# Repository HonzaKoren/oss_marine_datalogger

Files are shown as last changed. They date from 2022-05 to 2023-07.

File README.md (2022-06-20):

# OSS Marine Datalogger
OSS datalogger for any sailing fan including support of set of gadgets to get real data to your sailing history.

# Aim
Let's create a set of hardware and software, so you can log your sailing trips under the open data and with as much detail as suits you.
For look under the hood look at [architecture](architecture.md).

# Kick it up&running
A thorough [guide to make your Rasberry your personal tracker](qsg.md)

# External guides and inspirations
[See more](external_links.md)

# Expected hardware
- [Wind speed and direction sensor](wind_measurement.md)
- [Microcontroller Zero W](microcontroller.md)
- Any power bank with USB port to power up whole solution
- GPS/Galileo/GLONASS receiver
- Accelerometer (for anchor alarm and yacht waving compensations)
- Barometer (for weather alarms)

[Bill of material](bom.md)

# Standard wiring
[For no configuration customization use standard wiring schema.](wiring.md)

# Features
- Web interface to be used for visualisations
- Possibility to use WiFi internet connection to share data to any configured server supporting documented REST API
  - Select the data sets to be shared
  - Select the sharing frequency per dataset
  - Global share on/off
- Possibility to set asynchronous commands
  - Managed "cron" jobs
  - Alarms
  - Timed events to start/stop sharing
  - Any command possible to run at given time and frequency in general
- Possibility to set up a reaction to event (now primary intended for anchor alarm)
  - Event sources:
    - Accelerometer (broach logging, dangerous tilt)
    - GPS
      - position offset (anchor alarm)
      - point on map (turning or target point)
      - point connection (i.e. for start or finish during races)
    - Barometer (air pressure drop)
    - Wind speed (reefing alarm)
- Possibility to store Windy data for current location along with tracking data

Want more? Look, if we [plan it](backlog.md).

# Open Points
- Check out the possibility to broadcast data via BTLE to mobile apps
- Source of navy maps

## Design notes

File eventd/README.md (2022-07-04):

# Event daemon

Collects all events, mainly buttons, but in the future an async (cron) events, location offset alarm, environmental thresholds, etc.

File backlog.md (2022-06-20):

# Backlog and ideas

- Create an OSS anemometer
- Create an OSS wind speed sensor
- Log manouvre based on menu action
- Anchor alarm
- Windy forecast download and correlation

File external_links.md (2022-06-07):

# Interesting or guiding links

- [Guide to kick your Raspberry Pi up&running](https://www.raspberrypi.com/documentation/computers/getting-started.html)
- If you want to have your RPi accessible over the network in a [headless setup](https://www.windowscentral.com/how-set-headless-raspberry-pi-windows-10), try this guide
- [Guide to build a GPS tracking device from RPi Zero](https://studyexplorer.medium.com/build-your-own-gps-tracking-system-raspberry-pi-zero-w-2020-6b3ecf55615e)

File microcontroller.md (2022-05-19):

# Microcontroller

[Raspberry Pi Zero W](https://www.raspberrypi.com/products/raspberry-pi-zero-w/) for controlling all data inputs and handling all SW features.

## ToDo
- Verify performance on the go!

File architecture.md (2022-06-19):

# Logger Architecture

## Data collectors
### NMEA GPS module
```mermaid
flowchart TD;
    subgraph "NMEA GPS module";
        Init(Get sensor data) --> SplitRecord(Get first whole record);
        SplitRecord --> IdentifyRecord(Identify NMEA record type);
        IdentifyRecord --> ParseRecord{Parse record by type};
        ParseRecord -->|Location| LocationSave(fa:fa-compass Save position);
        ParseRecord -->|Time| TimeValidate{fa:fa-clock Local time invalid?};
        ParseRecord -->|Direction| DirectionSave(fa:fa-location-arrow Save direction);
        DirectionSave --> DirectionSegment[Direction segment];
        LocationSave --> LocationSegment[Location segment];
        LocationSegment --> ShMemUpdate[Publish to shmem];
        TimeValidate -->|+| SystimeUpdate(Update systime);
        SystimeUpdate --> TimeSegment[Time segment];
        TimeValidate -->|-| TimeSegment[Time segment];
        TimeSegment --> ShMemUpdate(Publish to shmem);
        DirectionSegment --> ShMemUpdate[Publish to shmem];
    end;
```

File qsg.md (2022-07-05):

# Quick Start Guide

## Preparation and tools you'll need
1. SSH client
    1. Linux has SSH client usually as a part of default installation, no pain
    1. Macos has some variety of options, [try this guide](https://www.makeuseof.com/best-ssh-clients-mac/)
    1. Windows has an excellent free SSH terminal emulation called [Putty](https://www.ssh.com/academy/ssh/putty/windows)

## Marine Logger setup
1. Take your Raspberry and make an initial setup as is [very well documented](external_links.md)
1. Connect to your Raspberry as pi user and:
    1. Download latest stable copy of Marine Logger code
    1. Run setup
    1. Connect to Marine Logger web UI (automatically generated admin password is on your SSH terminal screen)
    
### Download latest stable copy of Marine Logger code
```bash
sudo apt update
sudo apt install -y git
cd ~
git clone https://github.com/HonzaKoren/oss_marine_datalogger.git
```

### Run setup
```bash
cd ~/oss_marine_datalogger
./install.sh
```
Or alternatively as a single liner
```bash
sudo apt update && sudo apt install -y git && cd ~ && git clone https://github.com/HonzaKoren/oss_marine_datalogger.git && cd ~/oss_marine_datalogger && ./install.sh
```
### Connect to Marine Logger web UI
Open https://<your_datalogger_IP_address_used_for_SSH_already>/
Default superuser of Marine Datalogger is <em>admin</em>, initial password for that user was generated and shown in the previous step.
If you have lost for any reason the secure password, simply re-run previous step, the installation will be performed again and password re-generated. All your settings made till then will be lost as well. Consider this step a "factory reset".

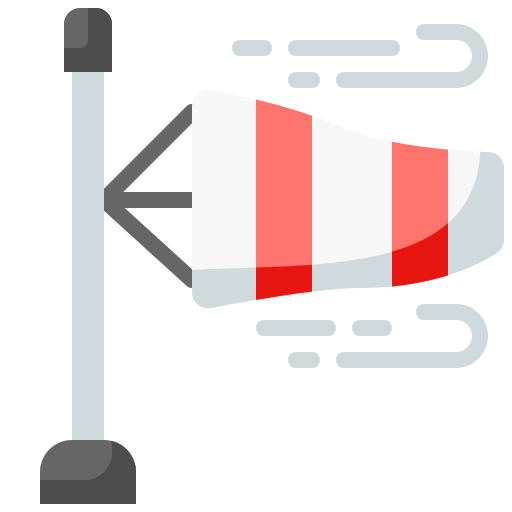
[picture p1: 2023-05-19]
web/static/web/img/windy.512x512.png

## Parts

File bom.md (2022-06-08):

# Bill of Material

1. Microcontroller: [Raspberry Pi 2 B](https://www.raspberrypi.com/products/raspberry-pi-2-model-b/) for future use [Raspberry Pi Zero 2 W](https://www.raspberrypi.com/products/raspberry-pi-zero-2-w/) is intended to save power
1. Location + SoG: [GPS/Beidou/GLONASS/Galileo/QZSS/SBAS Receiver](https://wiki.seeedstudio.com/Grove-GPS-Air530/)
1. USB connectivity for RPi 2 B (Zero 2 W has WiFi built in): Any microdongle ATM I'll use Ralink RT5370 (USB ID 148f:5370)
1. BT connectivity for RPi 2 B (Zero 2 W has BTLE built in): Any microdongle ATM I'll use Cambridge Silicon Radio (USB ID 0a12:0001)
1. Wind measurement - two options:
   1. Wireless over BT [Ultrasonic Portable Solar wind meter](https://calypsoinstruments.com/shop/product/ultrasonic-portable-solar-wind-meter-2)
   1. Wireless over BT, no solar power [Ultrasonic Portable Mini wind meter](https://calypsoinstruments.com/shop/product/cmi1022-ultrasonic-portable-mini-wind-meter-73)
   1. Wired over NMEA 0183 [Veinasa-CXS02B-N NMEA-0183](https://www.aliexpress.com/item/1005003788117590.html) + [NMEA 0183 to USB convertor](https://digitalyacht.co.uk/product/usb-nmea-adaptor/)
   1. Wired over modbus [MINI SIZE ULTRASONIC INTEGRATED WIND SPEED SENSOR AND WIND DIRECTION SENSOR](https://www.aliexpress.com/item/1005004105582503.html)
   1. [Modbus2USB converter](https://www.aliexpress.com/item/1005003076597700.html)
1. Compass
1. High capacity power bank: ATM I'll use solar water proof like [this Sandberg](https://www.czc.cz/sandberg-solarni-outdoorova-powerbanka-24000mah-cerna/233773/produkt)
1. 24x M2x8 metric screw for fixing all featured Grove modules
1. 5x M2.5x8 screw for fixing Rasberry board and for better haptic experience with lif buttons (might be replaced in the future by printed parts)

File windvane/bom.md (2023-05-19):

# Bill of material

## Standards

1. Joining screws ISO 10642 A4 M 2X8 (head border inset 1.32 x 1.1 mm for 3D design)

## Summary
- Joints: 14x Inbus DIN 912 M5x45 inox A4
- Joints: 14x Self locking nut DIN 985 M5 inox A4
- Axis&Windvane tip: 150 mm threaded rod M4 inox A4
- Axis&Windvane tip: 10x Self locking nut DIN 985 M4 inox A4
- Axis: 2x 627-2RS 7x22x7 Full ceramic sealed bearing
- Sensors&Power controller front: 19x M2x6 screw DIN 965 inox inox A4 (eventually DIN 7991, ISO 10642) - Philips or inbus
- Bottom lid&Power controller: 12x M2x8 screw DIN 965 inox inox A4 (eventually DIN 7991, ISO 10642) - Philips or inbus
- Anemometer fixing screw: 1x Inbus headles inox screw M5x5 DIN 914 inox A4
- Boxes insulation: 976 mm insulation 1mm rubber

## Used by parts
- 1x Body tilting joint screw - [Inbus DIN 912 M5x45 A4](http://www.spojovaci-material.net/sp/srouby/valcova-a-zaoblena-hlava/valcova-imbus-din-912/nerezova-ocel/a4-70/sroub-valcova-hlava-inbus-din-912-m5x45-nerez-a4-15187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)
- 2x Tilting joint peg screw - [Inbus DIN 912 M5x45 A4](http://www.spojovaci-material.net/sp/srouby/valcova-a-zaoblena-hlava/valcova-imbus-din-912/nerezova-ocel/a4-70/sroub-valcova-hlava-inbus-din-912-m5x45-nerez-a4-15187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)
- 2x Backstay screw - [Inbus DIN 912 M5x45 A4](http://www.spojovaci-material.net/sp/srouby/valcova-a-zaoblena-hlava/valcova-imbus-din-912/nerezova-ocel/a4-70/sroub-valcova-hlava-inbus-din-912-m5x45-nerez-a4-15187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)
- 5x Holder nuts - [Self locking inox nut DIN 985 M5 A4](http://www.spojovaci-material.net/sp/matice/sestihranne-pojistne/s-nylon-vlozkou-din-985/nerezova-ocel/a4/matice-samojistna-din-985-m5-nerez-a4-15580.html)
- 1x Wind vane axis screw - [65mm A4 závitová tyč]()
- 3x Wind vane shaft nuts - [Self locking inox nut DIN 985 M4 A4](http://www.spojovaci-material.net/sp/matice/sestihranne-pojistne/s-nylon-vlozkou-din-985/nerezova-ocel/a4/matice-samojistna-din-985-m4-nerez-a4-15579.html)
- 3x Fixing screw - [Inbus headless innox screw M5x5 DIN 914 A4](https://eshop.killich.cz/eshop/sroub-m5x5-a4-nerez-staveci-hrot-din-914-iso-4027_9145905005.html)
- 8x Lid & compas fixing screws - [Philips M2x5 DIN 965 A4]()

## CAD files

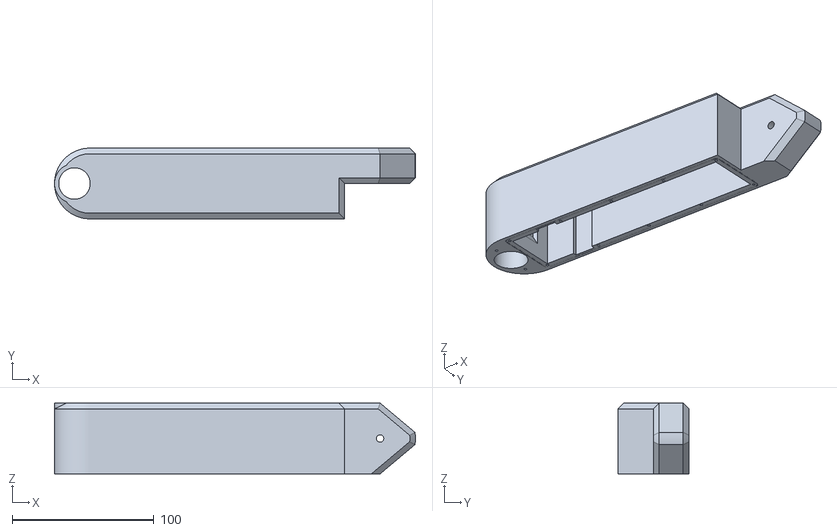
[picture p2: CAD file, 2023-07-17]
windvane/3dprint/Yacht Windvane - Main Body.stl
255.0 x 50.0 x 50.0

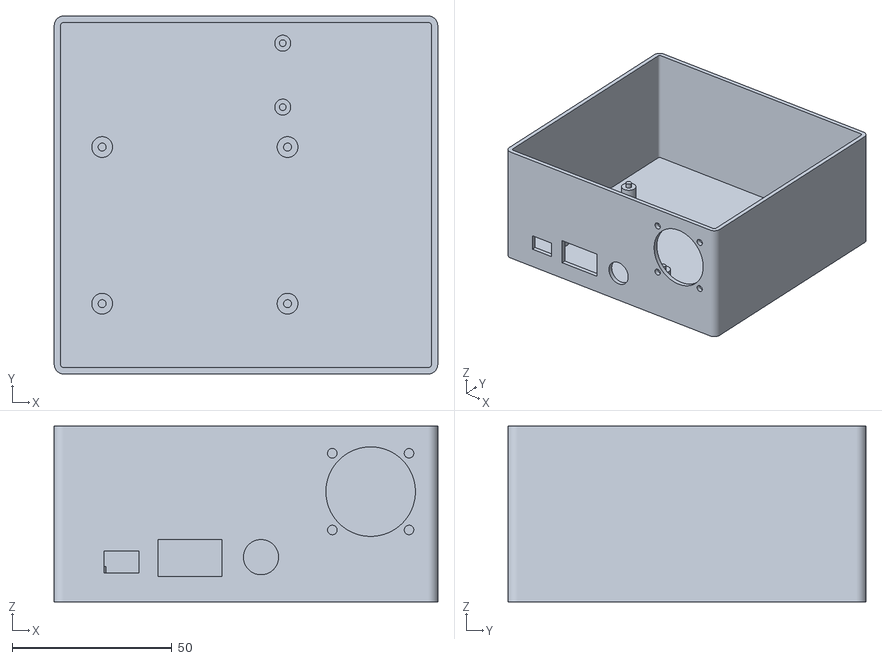
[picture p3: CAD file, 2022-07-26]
3D_print/Box.RPi.2-3-3b.stl
120.0 x 112.0 x 55.0

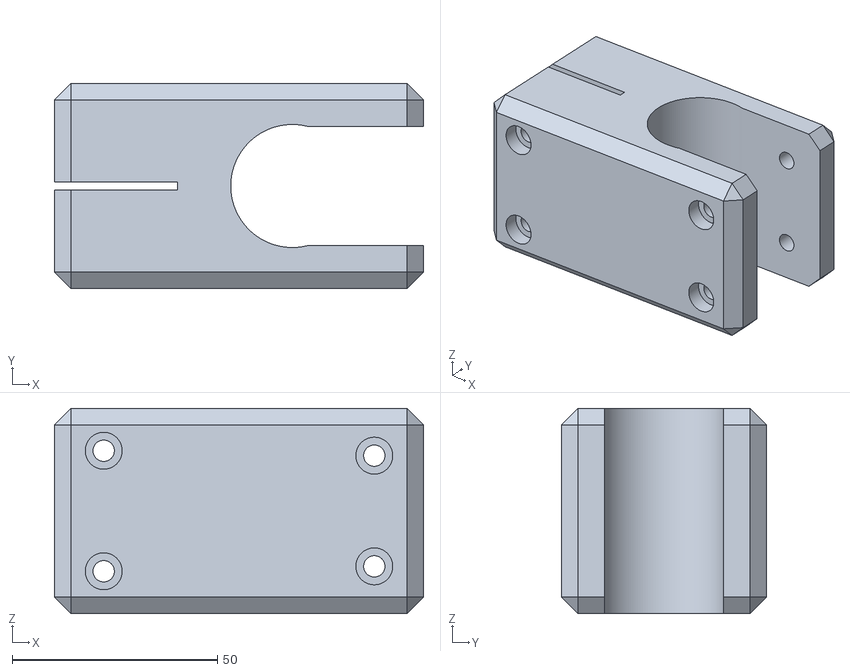
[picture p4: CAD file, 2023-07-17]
windvane/3dprint/Yacht Windvane - Backstay clip.stl
90.0 x 50.0 x 50.0

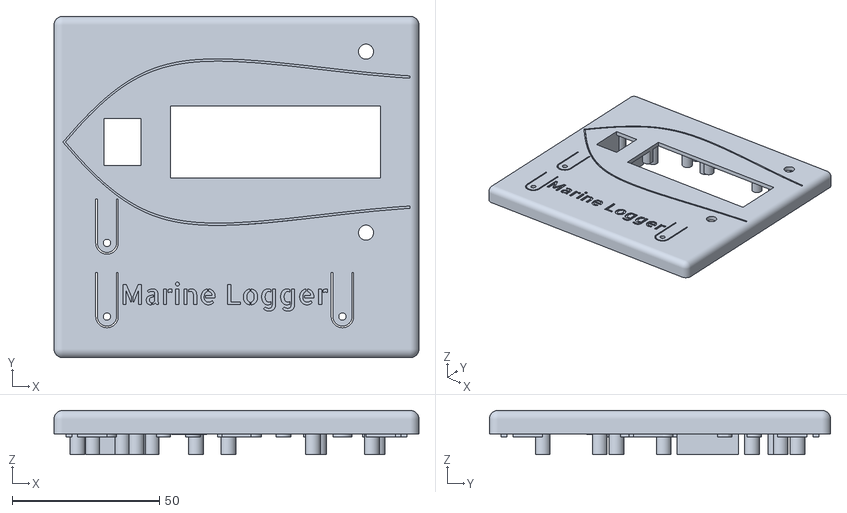
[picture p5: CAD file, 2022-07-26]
3D_print/Lid.RPi.2-3-3b.stl
124.0 x 116.0 x 15.0

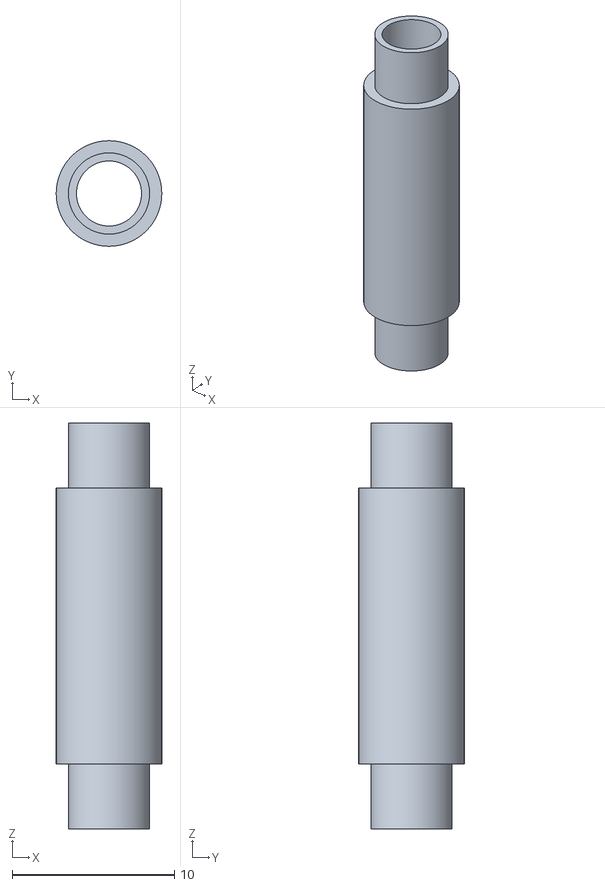
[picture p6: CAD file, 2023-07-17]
windvane/3dprint/Yacht Windvane - Anemometer Core.stl
6.50 x 6.50 x 25.0

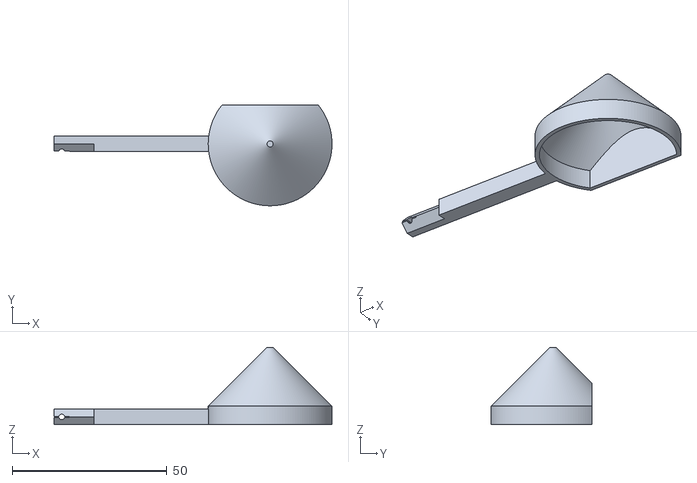
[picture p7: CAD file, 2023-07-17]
windvane/3dprint/Yacht Windvane - Anemometer Cap.stl
89.8 x 32.5 x 25.0

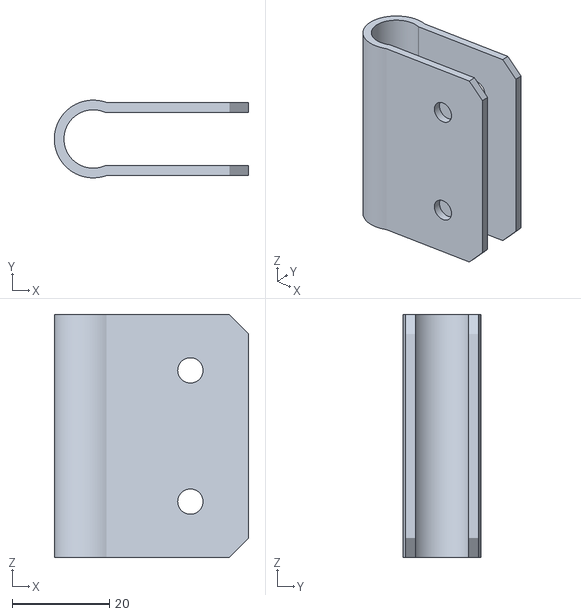
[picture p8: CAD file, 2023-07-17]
windvane/3dprint/Yacht Windvane - Backstay Inset 16-12mm.stl
40.0 x 16.0 x 50.0

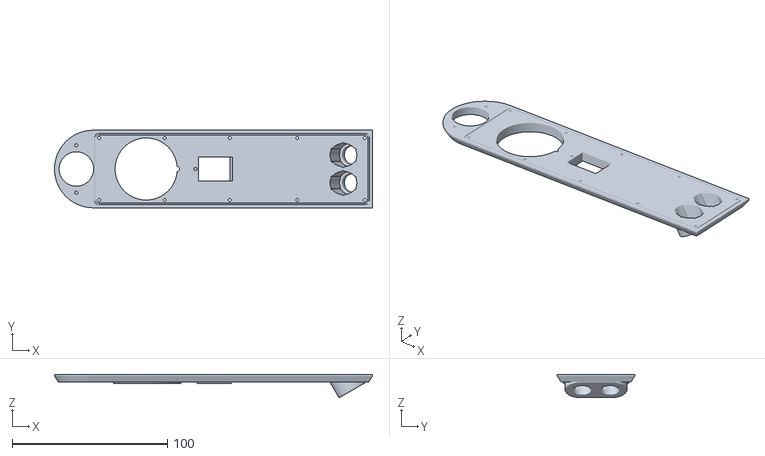
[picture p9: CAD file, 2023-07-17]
windvane/3dprint/Yacht Windvane - Bottom lid.stl
205.0 x 50.0 x 14.9

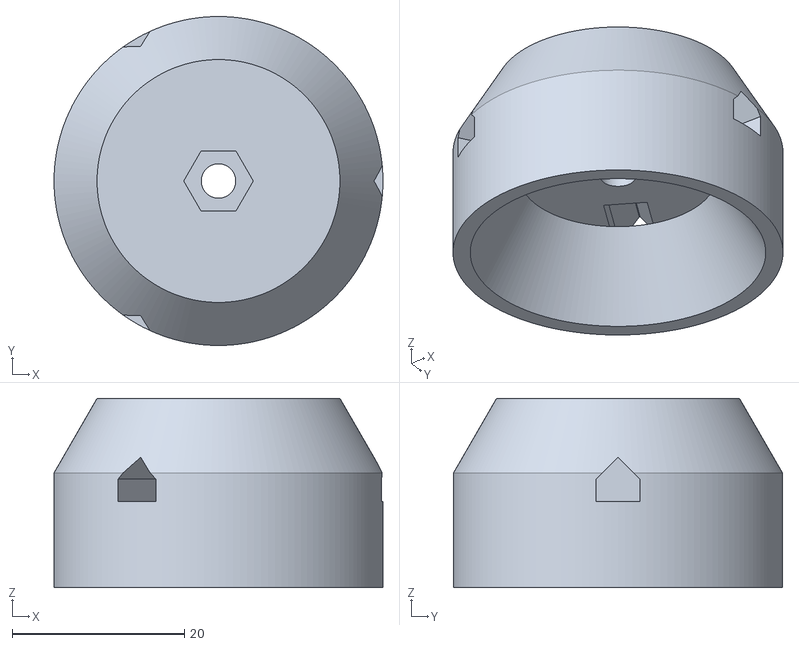
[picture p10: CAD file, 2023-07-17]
windvane/3dprint/Yacht Windvane - Anemometer Body.stl
38.2 x 38.2 x 22.0

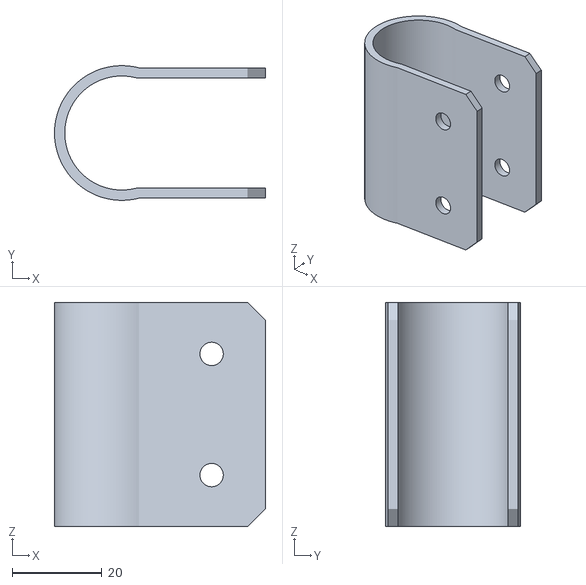
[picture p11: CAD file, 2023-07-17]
windvane/3dprint/Yacht Windvane - Backstay Inset 30mm-1in.stl
47.0 x 30.0 x 50.0

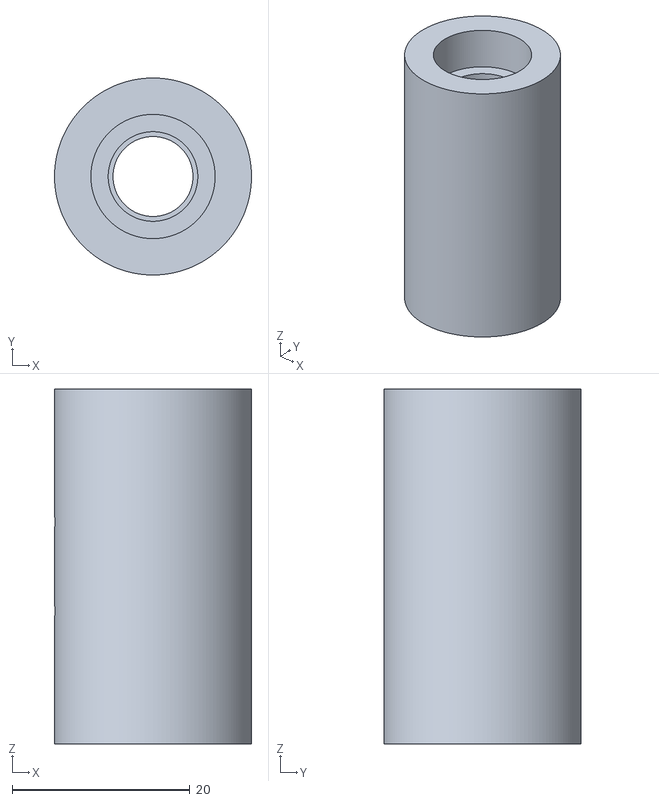
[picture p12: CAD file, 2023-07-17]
windvane/3dprint/Yacht Windvane - Anemometer Holder.stl
22.2 x 22.2 x 40.0

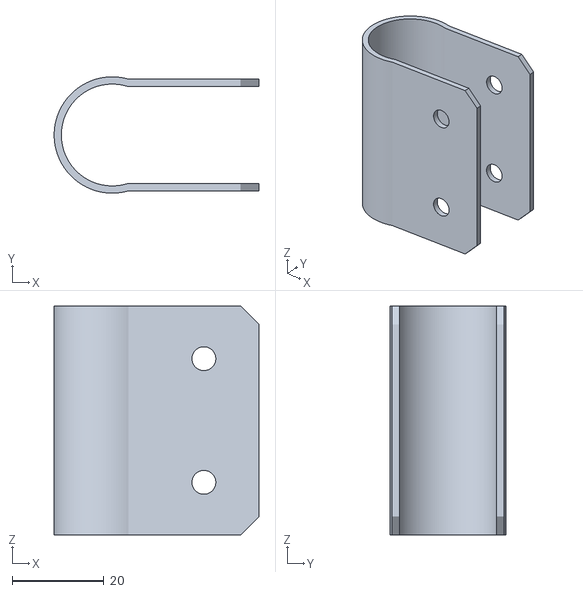
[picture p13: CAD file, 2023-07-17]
windvane/3dprint/Yacht Windvane - Backstay Inset 1in-0.875in.stl
44.7 x 25.4 x 50.0

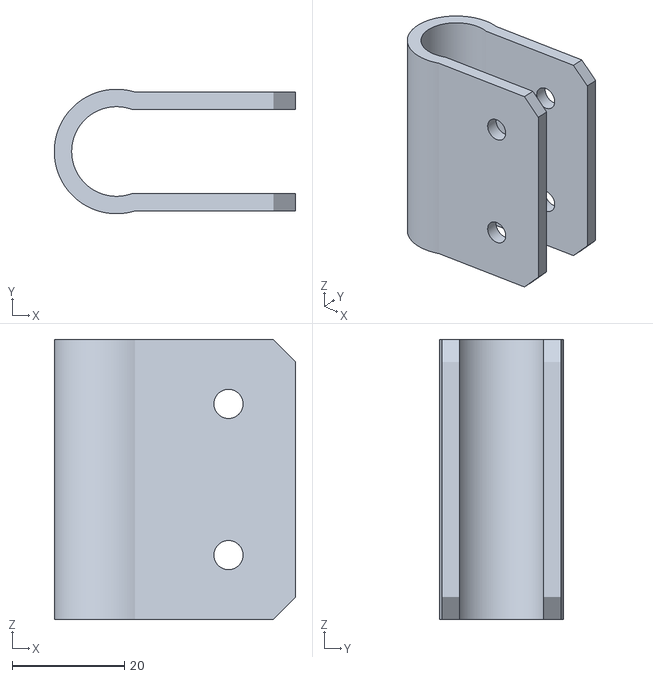
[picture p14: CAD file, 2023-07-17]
windvane/3dprint/Yacht Windvane - Backstay Inset 0.875in-16mm.stl
43.1 x 22.2 x 50.0

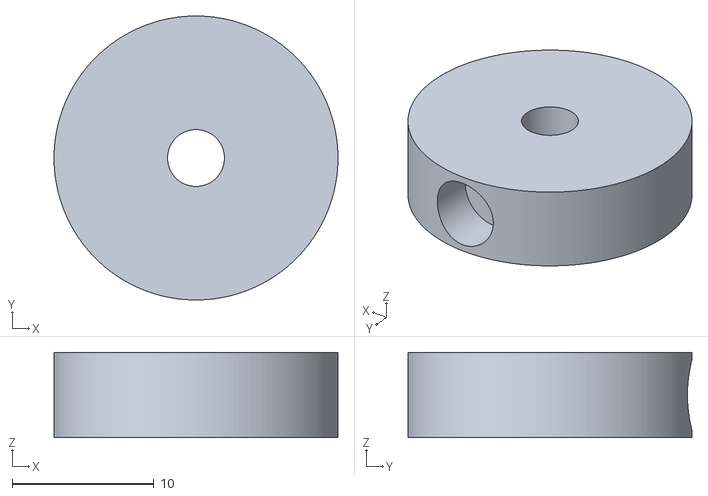
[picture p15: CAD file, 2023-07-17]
windvane/3dprint/Yacht Windvane - Anemometer Magnetic disc.stl
20.0 x 20.0 x 6.00

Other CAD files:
windvane/3dprint/Yacht Windvane - Backstay Inset 12-7mm.stl
windvane/3dprint/Yacht Windvane - ESP8266 socket.stl
windvane/3dprint/Yacht Windvane - SP power controller.stl
windvane/3dprint/Yacht Windvane - Solar Panel Holder.stl
windvane/3dprint/Base Station - Box.stl
windvane/3dprint/Base Station - Lid.stl
windvane/3dprint/Yacht Windvane - Axis mounting tool.stl
windvane/3dprint/Yacht Windvane - ESP8266 socket lid.stl
windvane/3dprint/Yacht Windvane - Flap carrier.stl
windvane/3dprint/Yacht Windvane - Flap.stl
windvane/3dprint/Yacht Windvane - GE outlet key.stl
windvane/3dprint/Yacht Windvane - GX12 Connector Thin Cable Fixer.stl
windvane/3dprint/Yacht Windvane - Joining peg.stl
windvane/3dprint/Yacht Windvane - Nut 7mm key shallow.stl
windvane/3dprint/Yacht Windvane - Nut 7mm key.stl
windvane/3dprint/Yacht Windvane - Peg square inside.stl
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

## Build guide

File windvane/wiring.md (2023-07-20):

# Arduino Nano module wiring

## Components

- Controller: Arduino Nano
  - https://www.laskakit.cz/arduino-nano-r3--atmega328p-klon--nepripajene-piny/
- Local storage **SDC**: SD Card reader (SPI, 3V3/**+5V** (from SPI, not common wire)) - 6wire flat
  - https://dratek.cz/arduino/993-ctecka-microsd-karet.html
  l
  - Connected to Nano SPI top header
- Location **LOC**: Ublox Neo-7M (SoftwareSerial, 3V3/**+5V**) - 5wire JST
  - https://dratek.cz/arduino/1733-gps-satelitni-urceni-polohy-neo-7m-modul.html
  - https://dratek.cz/docs/produkty/0/474/1502177743.pdf
- Temperature&Humidity **DHT**: DHT22 (DigitalRead, **3V3**/+5V) - 3wire JST
  - https://dratek.cz/arduino/1188-dht22-teplomer-a-vlhkomer-digitalni.html
  - https://dratek.cz/docs/produkty/0/56/1455993178.pdf
- Anemometer **ANE**: Hall sensor KY-003 (DigitalRead, 3V3/**+5V**) - 3wire JST
  - https://dratek.cz/arduino/7717-halluv-senzor-modul-ky-003.html
  - S pin for digital input
  - - for GND
  - Middle for VIN
- Wireless Serial **WSER**: HC-12 (SoftwareSerial + DigitalWrite, **3V3**/+5V) - 5wire JST
  - https://dratek.cz/arduino/1394-433mhz-hc-12-si4463-wireless-serial-port-modul-1000m.html
  - https://dratek.cz/docs/produkty/1/1301/1473675078.pdf
- Movement detection **ACC**: MPU6050 Gyroscope (I2C, **3V3**) - 5wire JST
  - https://www.laskakit.cz/arduino-gyroskop-a-akcelerometr-gy-521--mpu6050/
  - https://www.laskakit.cz/user/related_files/mpu-6050_datasheet_v3_4.pdf
- Barometric pressure **BAR**: BMP280 (I2C, **3V3**) - 5wire JST
  - https://www.laskakit.cz/arduino-senzor-barometrickeho-tlaku-a-teploty-bmp280/
- Compass **CMP**: HMC5883L (I2C, **3V3**) - 5wire JST
  - https://www.laskakit.cz/3-osy-magnetometr-a-kompas-hmc5883l/
  - https://github.com/adafruit/Adafruit_HMC5883_Unified
  - https://www.laskakit.cz/user/related_files/hmc5883l.pdf
- Wind direction **DIR**: AS5600 (I2C, 3V3/**+5V**) - 5wire JST
  - https://www.laskakit.cz/magneticky-rotacni-enkoder-as5600--i2c--pwm/
  - https://www.laskakit.cz/user/related_files/bst-bmp280-ds001-11.pdf

## Nano pins

- A0 - Battery voltage
- D2 - D12 - Digital pins
  - D2: Ublox Neo TX SoftwareSerial
  - D3: Ublox Neo RX SoftwareSerial
  - D4: Ublox Neo PPS DigitalRead (time pulse)
  - D5: HC-12 TX SoftwareSerial
  - D6: HC-12 RX SoftwareSerial
  - D7: HC-12 Set DigitalWrite
  - D8: DHT22 DigitalRead 
  - D9: Hall sensor DigitialRead
  - D10
  - D11
  - D12

| Use | PIN | :::<br>SD Card SPI | PIN  | Use |
|:---: |:---:|:---: |:----:|:---: |
| ___ | TX  | | VIN  | ___ |
| ___ | RX  | | GND  | All chip GND |
| ___ | RST | | RST  | ___ |
| ___ | GND | | +5V  | ___ |
| LOC TX white | D2  | | A7 | ___ |
| LOC RX yellow | D3  | | A6 | ___ |
| LOC PPS orange| D4  | | A5 | All I2C SCL  |
| WSER TX white | D5  | | A4 | All I2C SDA  |
| WSER RX yellow | D6  | | A3 | ___ |
| WSER Set orange| D7  | | A2 | ___ |
| DHT | D8  | | A1 | ___ |
| ANE | D9  | | A0 | ___ |
| SDC CS  | D10 | | AREF | ___ |
| ___ | D11 | | 3V3  | All chip VIN |
| ___ | D12 | | D13  | ___ |
| | | USB | | |

### SPI Connector on top of Nano R3 to be used with SDCard module

Taken here: http://lab.dejaworks.com/arduino-nano-sd-card-connection/

When looking from top and miniUSB on left, there are 6 pins on thi right side. This is its use:

|  1 | 2 |
|:----:|:---:|
| GND  | Unused |
| MOSI | SCK |
| VCC  | MISO<br>MOSO |

Sixth pin called CS is connected to digital pin.

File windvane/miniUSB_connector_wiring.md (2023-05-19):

# MiniUSB connector wiring

| Pin | Purpose | Male cable color |
| :-: | :-: | :-- |
| 1.  | VCC | Red |
| 2.  | D- | White |
| 3.  | D+ | Green |
| 4.  | ID | Not connected |
| 5.  | GND | Black |

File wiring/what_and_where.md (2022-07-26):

# Standard Wiring

- RPISER: Air 530 GPS module
- D2: Humidity and temperature sensor DHT11
- D3: Green LED (D3 supports PWM)
- D4: Enter
- D5: Red LED (D5 suipports PWM)
- D6: Buzzer
- D7: Down
- D8: Up
- I2C3: RGB lighted two row LCD (text - 0x3e, RGB - 0x62)
- I2C2: Accelerometer (MPU9250 - 0x68) and barometer (BMP280 - 0x77)

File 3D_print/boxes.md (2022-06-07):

# Boxes

- RPi 2/3/3B box
  - [Onshape CAD model]](https://cad.onshape.com/documents/71e624099aa9e1f631a4b1f3/w/ef475eeba840bf2d2089c468/e/411b5dd9156907e709d1c501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)
  - [STL](Box.RPi.2-3-3b.stl)

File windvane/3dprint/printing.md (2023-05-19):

# Printing suggestions
- Everything 0.20 mm quality profile
- Unless mentioned elsewhere, the filament color is up to you, I used gray, but it's just an aesthetics
- For the best UV stability and sturdy bodies all filaments are PETG
- Fill up 50%

## Main body and Windvane axis (3 parts)
- 6 perimeters
- Supports on base plate
- Body rotate 180° to have top on the plate
- White PETG filament (white for the biggest albedo)

## Bottom lid, Flap carrier, Flap, ESP8266 and AS5600 socket, 3 mounting tools (8 parts)
- Bottom lid rotate 180°
- 5 perimeters
- No supports

## Backstay clip, 2 its insets and Tilting joint (4 parts)
- 6 perimeters
- Supports everywhere

# Windvane axis top (1 part)
- 6 perimeters
- Supports on base plate

# Power drive socket
- Rotation angle to fit the printing board 41.147 °

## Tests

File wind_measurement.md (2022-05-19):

# Wind speed and direction sensor

Let's start with something ready to use despite the fact it is somehow an expensive solution.
[This gadget covers all our needs](https://calypsoinstruments.com/shop/product/ultrasonic-portable-solar-wind-meter-2).

## Future plans
Using 3D printer, compass, RPi Zero, Arduino or any low power consumption microcontroller build up a wind vane and anemometer as cheap as possible.

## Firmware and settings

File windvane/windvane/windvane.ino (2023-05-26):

//
//    FILE: windvane.ino
//  AUTHOR: Jan Kořínek
// PURPOSE: Run windvane/anemometer/DHT22/Adafruit sensors
//    DATE: 2023-04-19
// Sensors: AS5600 - Magnetic rotary encoder
//          DHT22 - Temperature/humidity sensor
//          HMC5883L - magnetic compas
//          

#include <Adafruit_HMC5883_U.h>
#include <Adafruit_BMP280.h>
#include <Adafruit_Sensor.h>
#include <AS5600.h>
#include <DHT.h>
#include <ESP8266HTTPClient.h>
#include <ESP8266mDNS.h>
#include <ESP8266WebServer.h>   // Include the WebServer library
#include <ESP8266WiFi.h>
#include <ESP8266WiFiMulti.h> 
#include <FS.h>
#include <MPU6050_light.h>
#include <SPI.h>
#include <WiFiClient.h>
#include <Wire.h>

// Asynchronous ISR and variables declaration
ICACHE_RAM_ATTR void isrPulseHandler();
volatile bool measure_window_start = false; // Whether first measurement in a time window starts
volatile unsigned long curr_time = 0;       // Current time stamp
volatile unsigned long start_time = 0;      // Timestamp of measurement window start
volatile bool concurrency_lock = false;     // Prevent two semi parallel runs on bounce
volatile float wind = 0;                    // Wind speed in m/s
volatile unsigned long rpm = 0;             // Counted pulses
int wind_probe = D6;                        // Anemometer pin

// Set static IP identity
IPAddress local_IP(192, 168, 192, 102);
// Set your Gateway IP address
IPAddress gateway(192, 168, 192, 254);

IPAddress subnet(255, 255, 255, 0);
IPAddress primaryDNS(192, 168, 192, 254);   //optional


// MultiWiFi setup
ESP8266WiFiMulti wifiMulti;     // Create an instance of the ESP8266WiFiMulti class, called 'wifiMulti'

// Start webserver
ESP8266WebServer server(80);    // Create a webserver object that listens for HTTP request on port 80

// Set up DHT digital pin
#define DHTPIN D4     // Digital pin connected to the DHT sensor
#define DHTTYPE    DHT22     // DHT 22 (AM2302)
DHT dht(DHTPIN, DHTTYPE);

// Barometric pressure
Adafruit_BMP280 bmp; // use I2C interface

// Set up windvane sensor
AS5600 as5600;   //  use default Wire

// Set up compass
Adafruit_HMC5883_Unified mag = Adafruit_HMC5883_Unified(12345);

// Set up accelerometer
MPU6050 mpu(Wire);

void handleRoot();              // function prototypes for HTTP handlers
void handleNotFound();

struct DhtData;   // DHT22 data prototype

struct BmpData;   // BMP280 data prototype

struct MpuData;   // MPU6050 data prototype

unsigned int now = 0;

HTTPClient http;
WiFiClient client;
float cal_compass = 0.0;
float cal_windvane = 0.0;

// Enable platform reset
void(* resetFunc) (void) = 0;

void setup(void){
  Serial.begin(115200);         // Start the Serial communication to send messages to the computer
  // delay(10);
  Serial.println('\n');

  // Set up anemometer pin
  pinMode(wind_probe,INPUT_PULLUP);
  attachInterrupt(digitalPinToInterrupt(wind_probe), isrPulseHandler, FALLING);  //  function for creating external interrupts at wind_probe pin on falling (HIGH to LOW)
  start_time = micros();
  
  // Set up FS
  bool res = SPIFFS.begin();

  // Start DHT reader
  dht.begin();

  // Start compass reader
  mag.begin();

  // Start magnetic encoder
  as5600.begin(4);  //  set direction pin.
  as5600.setDirection(AS5600_CLOCK_WISE);  // default, just be explicit.

  // Set up default APs to try to connect to
  wifiMulti.addAP("koreni", "heslicko");   // add Wi-Fi networks you want to connect to
  wifiMulti.addAP("ossml", "MarineLogger");
  // wifiMulti.addAP("ssid_from_AP_3", "your_password_for_AP_3");

  Serial.println("Connecting ...");
  int i = 0;
  while (wifiMulti.run() != WL_CONNECTED) { // Wait for the Wi-Fi to connect: scan for Wi-Fi networks, and connect to the strongest of the networks above
    delay(50);
    Serial.print('.');
  }
  if (WiFi.SSID() == "ossml") {
    WiFi.config(local_IP, gateway, subnet, primaryDNS);
    Serial.println("Connected to an implicit SSID, setting static IP.");
  }
  Serial.println('\n');
  Serial.print("Connected to ");
  Serial.println(WiFi.SSID());              // Tell us what network we're connected to
  Serial.print("IP address: ");
  Serial.println(WiFi.localIP());           // Send the IP address of the ESP8266 to the computer

  if (MDNS.begin("meteo")) {              // Start the mDNS responder for esp8266.local
    Serial.println("mDNS responder started");
    MDNS.addService("http", "tcp", 80);
  } else {
    Serial.println("Error setting up MDNS responder!");
  }

  // Start barometer
  unsigned status;
  status = bmp.begin(0x76);
  if (!status) {
    Serial.println(F("Could not find a valid BMP280 sensor, check wiring or "
                      "try a different address!"));
    Serial.print("SensorID was: 0x"); Serial.println(bmp.sensorID(),16);
    Serial.print("        ID of 0xFF probably means a bad address, a BMP 180 or BMP 085\n");
    Serial.print("   ID of 0x56-0x58 represents a BMP 280,\n");
    Serial.print("        ID of 0x60 represents a BME 280.\n");
    Serial.print("        ID of 0x61 represents a BME 680.\n");
    while (1) delay(10);
  } else {
    Serial.print("BMP280 init status: ");
    Serial.println(status);
  }
  bmp.setSampling(Adafruit_BMP280::MODE_FORCED,     /* Operating Mode. */
                Adafruit_BMP280::SAMPLING_X2,     /* Temp. oversampling */
                Adafruit_BMP280::SAMPLING_X16,    /* Pressure oversampling */
                Adafruit_BMP280::FILTER_X16,      /* Filtering. */
                Adafruit_BMP280::STANDBY_MS_500); /* Standby time. */

  // Start MPU6050
  byte mpu_status = mpu.begin();
  Serial.print(F("MPU6050 status: "));
  Serial.println(mpu_status);
  // Calibrate
  mpu.calcOffsets(true,true);
  
  server.enableCORS(true);
  server.on("/resetUnit", resetFunc);       // Perform unit reset on demand
  server.on("/data.json", handleJSON);      // Serve dynamic data as JSON
  server.on("/data.txt", handleTXT);        // Serve dynamic data as Prometheus plain text
  server.serveStatic("/", SPIFFS, "/index.html");
  server.serveStatic("/", SPIFFS, "/");
  server.onNotFound(handleNotFound);        // When a client requests an unknown URI (i.e. something other than "/"), call function "handleNotFound"

  server.begin();                           // Actually start the server
  Serial.println("HTTP server started");

  // Get calibration from master node
  http.begin(client, "http://192.168.192.101/static/calibration/compass.txt");
  int httpCode = http.GET();
  String compass = http.getString();
  Serial.print("Compass calibration offset ");
  Serial.println(compass);
  cal_compass = compass.toFloat() * PI / 180;
  http.end();
  http.begin(client, "http://192.168.192.101/static/calibration/windvane.txt");
  httpCode = http.GET();
  String windvane = http.getString();
  Serial.print("Windvane calibration offset ");
  Serial.println(windvane);
  cal_windvane = windvane.toFloat();
  http.end();
  now = millis();
}

void loop(void){
  server.handleClient();                    // Listen for HTTP requests from clients
}

struct DhtData
{
  String temperature;
  String humidity;
};

struct BmpData
{
  String temperature;
  String pressure;
  String altitude;
};

struct MpuData
{
  String temperature;
  String accX;
  String accY;
  String accZ;
  String accAngleX;
  String accAngleY;
  String angleX;
  String angleY;
  String angleZ;
  String gyroX;
  String gyroY;
  String gyroZ;
};

DhtData getDHT() {
  // DHT22 
  DhtData _dht;
  if(isnan(dht.readTemperature())) {
    _dht.temperature = String(-65535);
  } else {
    _dht.temperature = String(dht.readTemperature());
  }
  if(isnan(dht.readHumidity())) {
    _dht.humidity = String(-65535);
  }
    _dht.humidity = String(dht.readHumidity());
  return _dht;
}

BmpData getBMP() {
  // BMP init
  BmpData _bmp;
  if (bmp.takeForcedMeasurement()) {
    _bmp.temperature = String(bmp.readTemperature());
    _bmp.pressure = String(bmp.readPressure());
    _bmp.altitude = String(bmp.readAltitude());
  } else {
    _bmp.temperature = String("-0.0");
    _bmp.pressure = String("-0.0");
    _bmp.altitude = String("-0.0");
  }
  return _bmp;
}

MpuData getMPU() {
  // MPU init
  MpuData _mpu;
  mpu.update();
  _mpu.temperature = String(mpu.getTemp());
  _mpu.accX = String(mpu.getAccX());
  _mpu.accY = String(mpu.getAccY());
  _mpu.accZ = String(mpu.getAccZ());
  _mpu.accAngleX = String(mpu.getAccAngleX());
  _mpu.accAngleY = String(mpu.getAccAngleY());
  _mpu.angleX = String(mpu.getAngleX());
  _mpu.angleY = String(mpu.getAngleY());
  _mpu.angleZ = String(mpu.getAngleZ());
  _mpu.gyroX = String(mpu.getGyroX());
  _mpu.gyroY = String(mpu.getGyroY());
  _mpu.gyroZ = String(mpu.getGyroZ());
  return _mpu;
}

String getVoltage() {
  float analog = analogRead(A0);
  float voltage = 4.2 * (analog / 1024);  // Max ESP input voltage * Digital sensor load
  return String(voltage);
};

String getDirection() {
  // Compass data
  sensors_event_t magData; 
  mag.getEvent(&magData);
  float azimuth = atan2(magData.magnetic.y, magData.magnetic.x) + cal_compass;
  if(azimuth < 0)
    azimuth += 2*PI;
  if(azimuth > 2*PI)
    azimuth -= 2*PI;  
  float azimuthDg = azimuth * 180/M_PI;
  return String(azimuthDg);  
}

String getWind() {
  // AS5600 wind direction
  float apparentWind = as5600.rawAngle() * AS5600_RAW_TO_DEGREES + cal_windvane;
  if(apparentWind < 0)
    apparentWind += 360;
  if(apparentWind > 360)
    apparentWind -= 360;  
  return String(apparentWind);
}

void handleJSON() {
  DhtData myDht = getDHT();
  BmpData myBmp = getBMP();
  MpuData myMpu = getMPU();
  
  String response = "{\"humidity_dht\": ";
  response += myDht.humidity;
  response += ", \"temperature_dht\": ";
  response += myDht.temperature;
  response += ", \"inner_temperature\": ";
  response += myBmp.temperature;
  response += ", \"air_pressure\": ";
  response += myBmp.pressure;
  response += ", \"altitude\": ";
  response += myBmp.altitude;
  response += ", \"direction\": ";
  response += getDirection();
  response += ", \"apparent_wind\": ";
  response += getWind();
  response += ", \"temperature_mpu\": ";
  response += myMpu.temperature;
  response += ", \"accX\": ";
  response += myMpu.accX;
  response += ", \"accY\": ";
  response += myMpu.accY;
  response += ", \"accZ\": ";
  response += myMpu.accZ;
  response += ", \"accAngleX\": ";
  response += myMpu.accAngleX;
  response += ", \"accAngleY\": ";
  response += myMpu.accAngleY;
  response += ", \"angleX\": ";
  response += myMpu.angleX;
  response += ", \"angleY\": ";
  response += myMpu.angleY;
  response += ", \"angleZ\": ";
  response += myMpu.angleZ;
  response += ", \"gyroX\": ";
  response += myMpu.gyroX;
  response += ", \"gyroY\": ";
  response += myMpu.gyroY;
  response += ", \"gyroZ\": ";
  response += myMpu.gyroZ;
  response += ", \"wind_speed\": ";
  response += String(wind);
  response += ", \"wind_pulses\": ";
  response += String(rpm);
  response += ", \"a0_data\": ";
  response += String(analogRead(A0));
  response += ", \"battery_voltage\": ";
  response += getVoltage();
  response += ", \"runtime\": ";
  response += String(millis());
  response += "}";
  server.send(200, "application/json", response);
}

void handleTXT() {
  DhtData myDht = getDHT();  // Read DHT
  BmpData myBmp = getBMP();
  MpuData myMpu = getMPU();
  // Acceleration
  // Wind speed
  // Timestamp
  // Calibrations 
  // Battery voltage and percentage
  // HTTP server request count
  String response = "humidity_dht " + myDht.humidity + "\n";
  response += "temperature_dht " + myDht.temperature + "\n";
  response += "inner_temperature " + myBmp.temperature + "\n";
  response += "air_pressure " + myBmp.pressure+ "\n";
  response += "altitude " + myBmp.altitude + "\n";
  response += "direction " + getDirection() + "\n";
  response += "apparent_wind " + getWind() + "\n";
  response += "temperature_mpu " + myMpu.temperature + "\n";
  response += "accX " + myMpu.accX + "\n";
  response += "accY " + myMpu.accY + "\n";
  response += "accZ " + myMpu.accZ + "\n";
  response += "accAngleX " + myMpu.accAngleX + "\n";
  response += "accAngleY " + myMpu.accAngleY + "\n";
  response += "angleX " + myMpu.angleX + "\n";
  response += "angleY " + myMpu.angleY + "\n";
  response += "angleZ " + myMpu.angleZ + "\n";
  response += "gyroX " + myMpu.gyroX + "\n";
  response += "gyroY " + myMpu.gyroY + "\n";
  response += "gyroZ " + myMpu.gyroZ + "\n";
  response += "wind_speed " + String(wind) + "\n";
  response += "wind_pulses " + String(rpm) + "\n";
  response += "a0_data " + String(analogRead(A0)) + "\n";
  response += "battery_voltage " + getVoltage() + "\n";
  response += "runtime " + String(millis()) + "\n";
  server.send(200, "text/plain", response);
}

void handleNotFound(){
  server.send(404, "text/plain", "404: Not found"); // Send HTTP status 404 (Not Found) when there's no handler for the URI in the request
}

//ISR function catching anemometer pulse
ICACHE_RAM_ATTR void isrPulseHandler()
{
  if(!concurrency_lock) {
    concurrency_lock = true;
    // Parallel run debounce
    // Get now to use it for pulse length and debounce
    curr_time = micros();
    // Debounce measurement sooner, than 20 ms
    unsigned long pulse_duration = curr_time - start_time;
    if(pulse_duration > 750) {
      if(!measure_window_start) {
        float pulse_length = (float)(pulse_duration / 1000);  // Pulse length in seconds
        wind = (float)(2400000.0 / (pulse_duration * 3.6));    // Device constant 1 pulse per second = 2,4 km/h, calc in m/s
        rpm++;
      }
      // Measurement was considered valid, shift start time
      start_time = curr_time;
      // Next measurement will not be taken as initial
      measure_window_start = false;
    }
    concurrency_lock = false;
  }
}

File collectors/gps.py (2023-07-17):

#!/usr/bin/env python3
import io
import os
from pathlib import Path
from shutil import move
import time

import pynmea2
import serial


ser = serial.Serial('/dev/serial0', 9600, timeout=1.0)
sio = io.TextIOWrapper(io.BufferedRWPair(ser, ser))

tmp_dir = "/home/pi/runtime/log"
tmp_log = os.path.join(tmp_dir, "gps.log")
dest_log = "/home/pi/runtime/log/gps.{}.log"
persistent = "/home/pi/data/"
persistent_write_offset = 60 # How long before copy log to persistent storage

last = 0

def init():
    # Check dirs
    for dir in (tmp_dir, persistent):
        if not os.path.isdir(dir):
            os.mkdir(dir)

init()

while 1:
    now = int(time.time())
    try:
        line = sio.readline()
        msg = pynmea2.parse(line)
    except UnicodeDecodeError:
        continue
    except serial.SerialException as e:
        print('Device error: {}'.format(e))
        break
    except pynmea2.ParseError as e:
        print('Parse error: {}'.format(e))
        continue
    # Write TMP file
    f = open(tmp_log, "a")
    f.write(f"{now} {repr(msg)}\n")
    f.close()

    # If history was not kept for offset seconds, move it to persitent storage
    if now - last > persistent_write_offset:
        dst = dest_log.format(int(time.time()))
        Path(tmp_log).rename(dst)
        move(dst, persistent)
        last = int(time.time())

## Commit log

2022-05-22 Add BoM
2022-05-23 Add cheap wired sensor
2022-05-23 Add no solar powered BT wind sensor
2022-06-07 Add 3D model for Raspberry Pi 2/3/3B with GrovePi+ module
    [Box.RPi.2-3-3b.stl, Lid.RPi.2-3-3b.stl]
2022-06-07 Add default wiring for GrovePi+
2022-06-08 Add screws to BoM
2022-06-20 Fine tune 3D models
    [Box.RPi.2-3-3b.stl, Lid.RPi.2-3-3b.stl]
2022-06-29 Add board tests so we can test wiring after successfull bootstrap
2022-06-29 Add pigpio to dependecies so we can work with I2C from python3
2022-06-29 Add I2C LCD availability test
2022-07-01 Add button detection routine to initial test
2022-07-02 Fix split filter usage
2022-07-03 Install grove system wide to compile I2C drivers
2022-07-04 Move WSGI socket and configure Django for UWSGI
2022-07-04 Add initial version of event daemon driving LCD and buttons
2022-07-05 Added Accel&Baro sensor
2022-07-06 Improve box layout
    - AIR530 module moved from box to lid to prevent damage of antenna wire
    - Add socket for 30mm fan on the box side
    - Open DHT11 socket so the air from fan can access it to speed up sensor reading and improve accuracy
    - Temporarily suspended front hole render in model to help air flow cool down whole box (exhaust will use HDMI and 3.5mm jack holes)
    [Box.RPi.2-3-3b.stl, Lid.RPi.2-3-3b.stl]
2022-07-14 Added Accel and Baro chips and I2C addresses
2022-07-14 Add RGB LCD I2C addresses
2022-07-26 Improve fan mount and lid disposition
    [Box.RPi.2-3-3b.stl, Lid.RPi.2-3-3b.stl]
2022-07-26 Add sample GPS records
2022-07-26 Add firxture source spreadsheet
    [configuration.fixture.source.ods]
2023-05-19 Remove unrequired sample
2023-05-19 Add initial version of windvane
    [Base Station - Box.stl, Base Station - Lid.stl, Yacht Windvane - Axis mounting tool.stl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]
2023-05-25 Switch to vanilla prometheus image
2023-05-26 Add calibration and speed up boot
2023-05-27 Update fixture source
    [configuration.fixture.source.ods]
2023-05-27 Prepare GPS, temperature and humidity loggers
2023-07-17 Re-work the backstay clip for easier print and more diameters
    [Yacht Windvane - Anemometer Body.stl, Yacht Windvane - Anemometer Cap.stl, Yacht Windvane - Anemometer Core.stl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]
2023-07-17 Document Arduino wiring
2023-07-17 Finalize wiring
2023-07-17 Add SPI connection to SD Card reader
2023-07-19 Document SDCard wiring to SPI pins
